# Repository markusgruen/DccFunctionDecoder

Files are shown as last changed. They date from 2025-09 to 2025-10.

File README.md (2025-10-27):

# DccFunctionDecoder

Hier klicken für deutsch: [Deutsche Doku](https://github.com/markusgruen/DccFunctionDecoder/blob/main/README_DE.md)

---

A simple DCC function decoder with 4 AUX channels. Compiles for an ATtiny402

Functionality:
- CV configurable
- 4 individual outputs
- 3 modes available for each output: FADE, BLINK, NEON
- Function mapping for F0...F20 for each output
- short and long address
- consist address

## Hardware
KiCad files are available in the `Hardware`-folder

The PCB has a size of approx. 7 by 7 mm. PCB is double-sided and only has standard components in the size of 0603 or larger to enable hand soldering of the decoder.

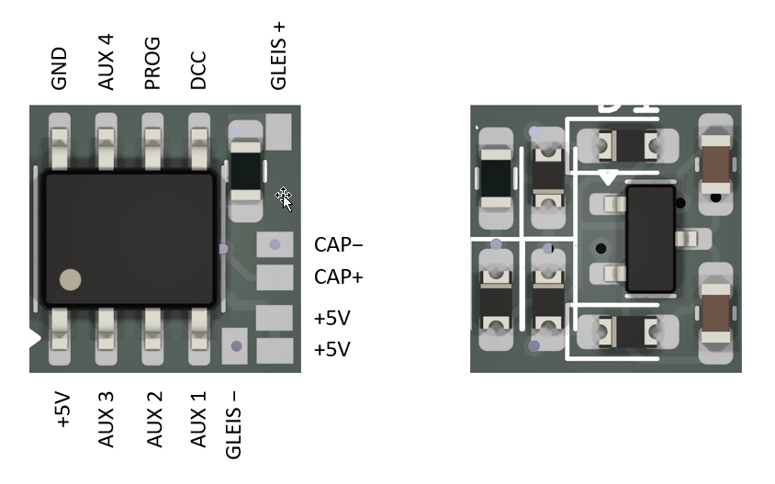
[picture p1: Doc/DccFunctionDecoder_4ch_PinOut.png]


## Software
The software can be compiled and flashed using the Arduino environment.

## Usage
### Flashing the software
You will require a standard USB-UART adapter (5V compatible). Connect the adapter as shown with the decoder. You **MUST NOT** connect the decoder's 5V with the UART-adapter. The LDO on the decoder does not like being reverse powered. Switch on the rail's power supply.

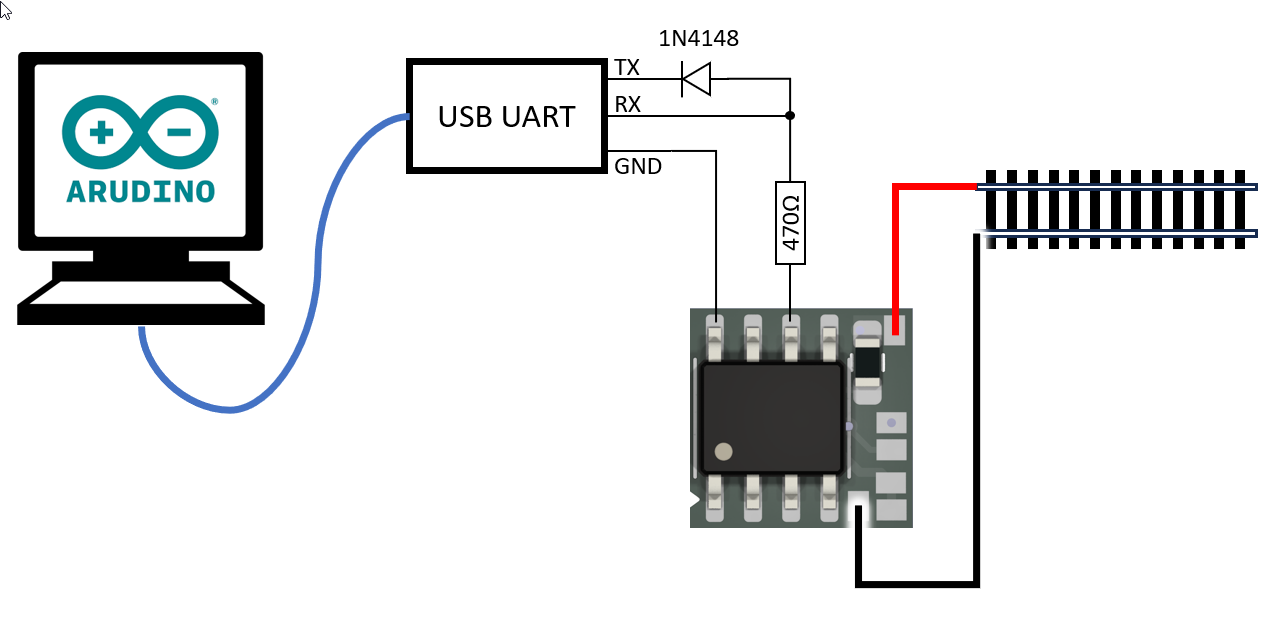
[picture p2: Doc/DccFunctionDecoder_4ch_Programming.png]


Select the appropriate COM port in the Arduino IDE and select `Sketch -> Upload using Programmer` (or hit **CTRL+SHIFT+U**). Just hitting the `Upload`-Button (or pressing **CTRL+U**) will not work.

### First usage of the decoder after flashing
Right after flashing, the Decoder is NOT yet ready for usage, as the ATtiny's EEPROM is still on factory default and the decoder therefore has an unknown address. You can already wire up the decoder as described in the following section. Then, perform a factory reset of the decoder by writing the value 8 to CV8, using the decoder's magic address 10239. In case you forgot your decoder's address, you can always perform CV writes using the magic address 10239. If you are using DecoderPro, proceed as shown below: 
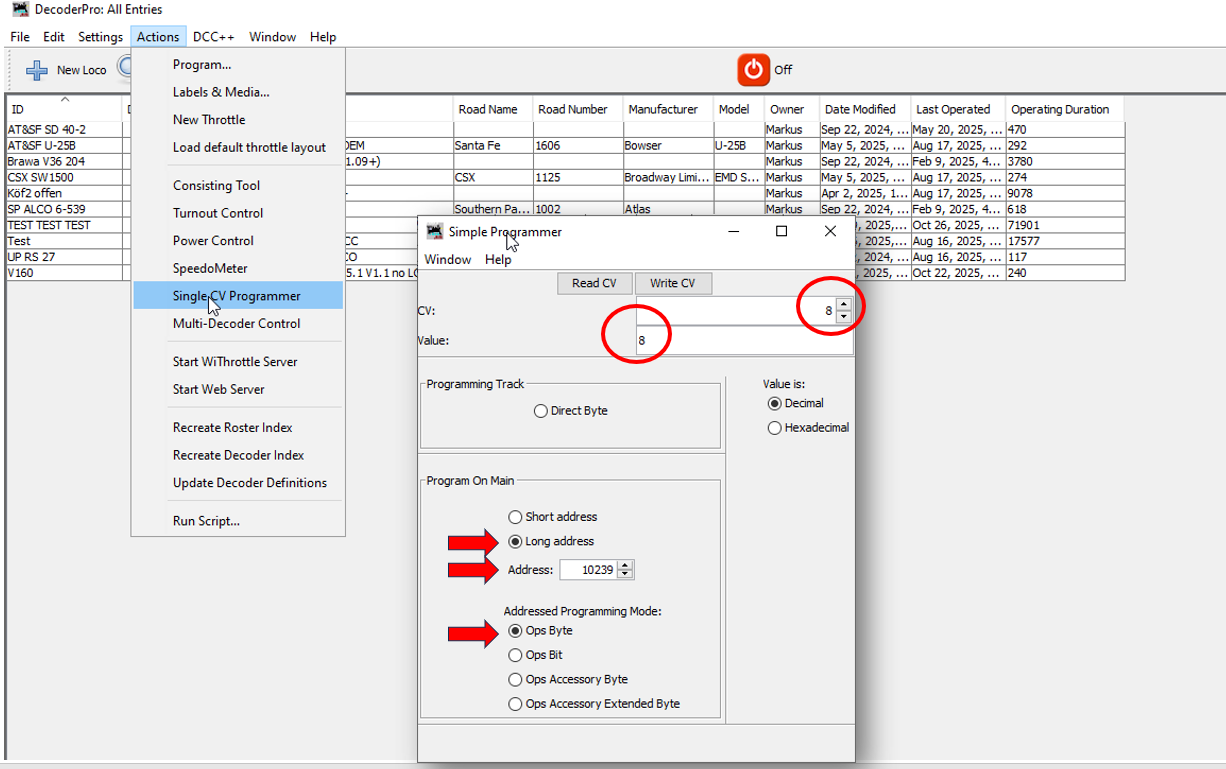
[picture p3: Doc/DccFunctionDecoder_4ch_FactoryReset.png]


### Using the decoder in a locomotive or wagon
Connect the LEDs as shown. Use appropriate resistors. The maximum current should be limited to 2 mA per LED. That does sound little but usually it is enough. Otherwise the LDO on the decoder gets too hot. 

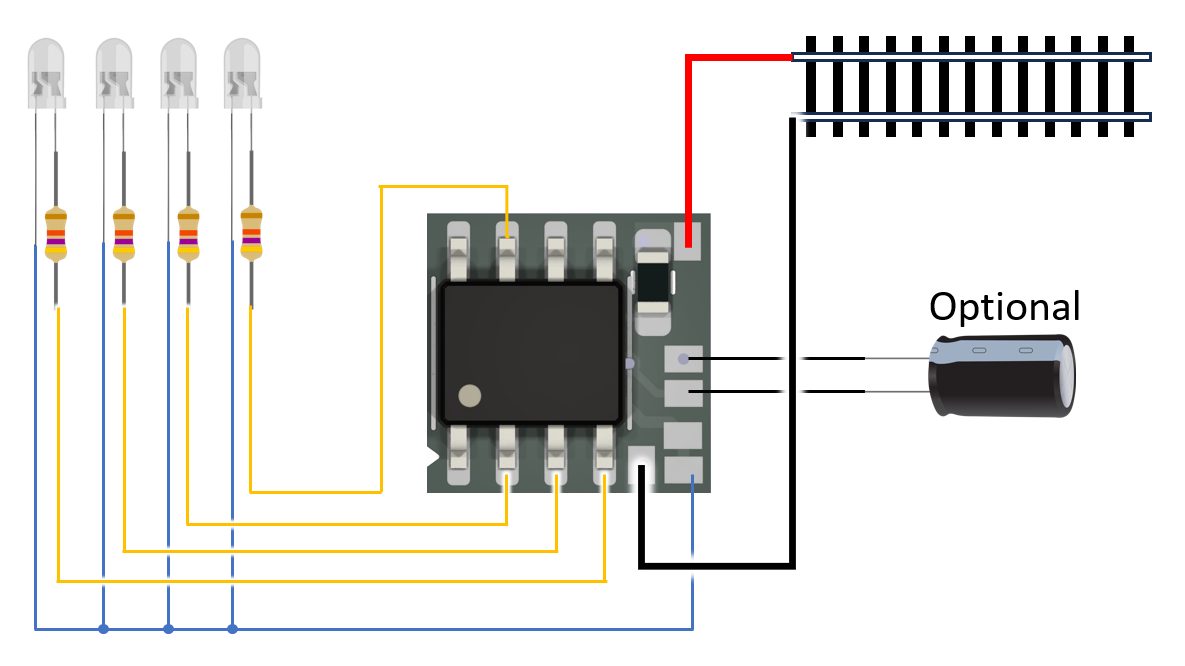
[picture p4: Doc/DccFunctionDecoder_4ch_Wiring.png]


### Programming CVs
The decoder ONLY supports Programming on Main (POM) mode. It cannot generate an ACK. For CVs see the following table below. The decoder will confirm each CV write with a short flash of all AUX channels. 

#### Programming the address
Special note on programming the address: If you want to change the decoder's address, you must do so in the following order:
1. program CV3 or CV17 and CV18 as desired.
2. program CV29 = 0 (short address) or CV29 = 32 (long address)

From then on, the decoder will only accept CV writes or commands to the new address. (it will of course still accept commands to its consist address)

#### Decoder reset
The decoder can be reset to its default CV values by writing CV8 = 8. This is confirmed by multiple short flashes of all AUX channels.

#### CV table

| CV | Type | range | default Value | Description |
|---|---|---|---|---|
| 1 | address | 1...127 | 3 | short address |
| 17 | long Address high byte | 192...255 | 195 | CV17 = 192 + (address / 256) |
| 18 | long address low byte  | 0...255 | 232 | CV18 = address mod 256 |
| 19 | consist address  | 0...255 | 0 | consist address |
| 29 | configuration byte  | 0...255 | 0 | CV29 = 0: short address;<br>CV29 = 32: long address |
| 33...35<br>36...38<br>39...41<br>42...44 | FunctionMap AUX n <br> (3 bytes for each AUX. The 3 bytes form a "word" with 24 bits)  | each CV: 0...255  | CV33 = 0b00000010 (F1) <br> CV36 = 0b00000100 (F2) <br> CV39 = 0b00001000 (F3) <br> CV42 = 0b00010000 (F4) <br> all others = 0  | Bit 0 = 1: AUX n controlled by F0<br> Bit 1 = 1: AUX n controlled by F1 <br>...<br> Bit 20 = 1 : AUX n controlled by F20 <br> Bit 21: reserved <br> Bit 22 = 1: AUX n only active when forward <br> Bit 23 = 1: AUX n only active when reverse |
| 57 <br> 58 <br> 59 <br> 60  | Output mode AUX n  | 0...2 | 0 | 0 = fade <br> 1 = neon <br> 2 = Blink |
| 65 <br> 66 <br> 67 <br> 68  | dimm value AUX n | 0...255 | 255 | 0 = off <br> ... <br> 255 = full brightness |
| 73 <br> 74 <br> 75 <br> 76  | fade speed AUX n | 0...255 | 0 | 0 = instant on/off <br> ... <br> 255 = very slow fading |
| 97 <br> 98 <br> 99 <br> 100 | blink on time AUX n  | 0...255  | 80 | value * 10ms = on-time during blink <br> (only active when CV57...60 = 2) |
| 105 <br> 106 <br> 107 <br> 108 | blink off time AUX n  | 0...255  | 150 | value * 10ms = off-time during blink <br> (only active when CV57...60 = 2) |

## License and Legal
Copyright 2025 by Markus Grün

Software licensed under GNU General Public License v3.0, see license file in `Software`-folder

Hardware (Schematics, Layout, etc.) licensed under CERN-OHL-P v2 or later, see license file in `Hardware`-folder

THE SOFTWARE AND SOURCES ARE PROVIDED "AS IS", WITHOUT WARRANTY OF ANY KIND, EXPRESS OR IMPLIED, INCLUDING BUT NOT LIMITED TO THE WARRANTIES OF MERCHANTABILITY, FITNESS FOR A PARTICULAR PURPOSE AND NONINFRINGEMENT. IN NO EVENT SHALL THE AUTHORS OR COPYRIGHT HOLDERS BE LIABLE FOR ANY CLAIM, DAMAGES OR OTHER LIABILITY, WHETHER IN AN ACTION OF CONTRACT, TORT OR OTHERWISE, ARISING FROM, OUT OF OR IN CONNECTION WITH THE SOFTWARE OR SOURCES OR THE USE OR OTHER DEALINGS IN THE SOFTWARE OR SOURCES.

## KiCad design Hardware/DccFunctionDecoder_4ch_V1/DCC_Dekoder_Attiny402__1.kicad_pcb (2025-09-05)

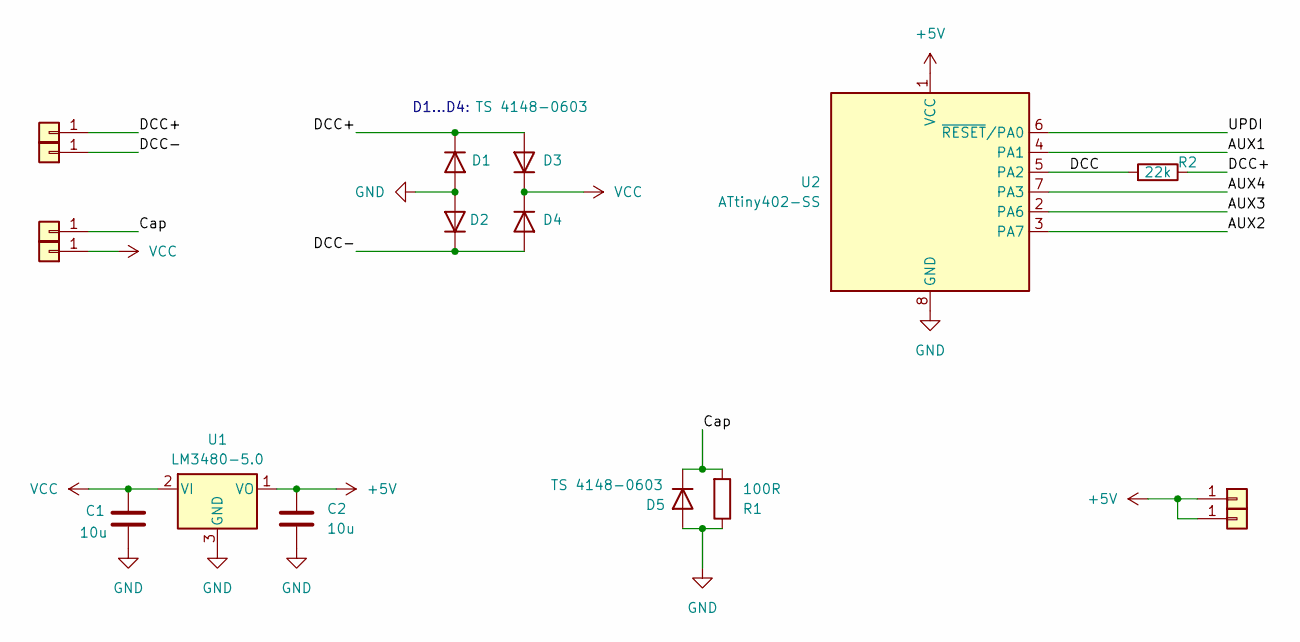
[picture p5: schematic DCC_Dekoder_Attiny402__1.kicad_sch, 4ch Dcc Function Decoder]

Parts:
C1, C2: 10u; C_0603_1608Metric_Pad1.08x0.95mm_HandSolder
D1, D2, D3, D4, D5: TS 4148-0603; D_0603_1608Metric_Pad1.05x0.95mm_HandSolder
J1, J2, J3, J4, J5, J7: Conn_01x01; Solderpad_1x_SMD_1.0x0.7
R1: 100R; R_0603_1608Metric_Pad0.98x0.95mm_HandSolder
R2: 22k; R_0603_1608Metric_Pad0.98x0.95mm_HandSolder
U1: LM3480-5.0; SOT-23
U2: ATtiny402-SS; SOIC-8_3.9x4.9mm_P1.27mm

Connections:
+5V: C2.1, J5.1, J7.1, U1.1 (VO), U2.1 (VCC)
/AUX1: U2.4 (PA1)
/AUX2: U2.3 (PA7)
/AUX3: U2.2 (PA6)
/AUX4: U2.7 (PA3)
/Cap: D5.1 (K), J2.1, R1.2
/DCC: R2.2, U2.5 (PA2)
/DCC+: D1.1 (K), D3.2 (A), J1.1, R2.1
/DCC-: D2.1 (K), D4.2 (A), J4.1
/UPDI: U2.6 (~RESET/PA0)
GND: C1.2, C2.2, D1.2 (A), D2.2 (A), D5.2 (A), R1.1, U1.3 (GND), U2.8 (GND)
VCC: C1.1, D3.1 (K), D4.1 (K), J3.1, U1.2 (VI)

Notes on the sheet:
D1...D4:

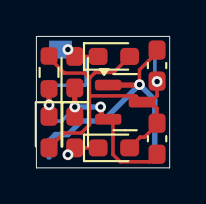
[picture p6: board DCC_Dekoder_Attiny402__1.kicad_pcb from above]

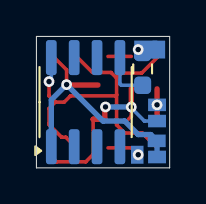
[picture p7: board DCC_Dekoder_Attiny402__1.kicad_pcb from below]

Board: 2 copper layers, 7.4 x 7.3 mm, 17 parts (8 on the bottom side), 7 nets.

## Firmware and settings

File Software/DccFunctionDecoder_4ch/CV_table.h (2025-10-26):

#ifndef CV_TABLE_H
#define CV_TABLE_H


#define DEFAULT_SHORT_ADDRESS 3
#define DEFAULT_LONG_ADDRESS 1000
#define MAGIC_ADDRESS  10239  // decoder can always be programmed using this address

//      EEPROMaddress    CV
#define SHORTADDRESS      1
#define LONGADDRESS1     17
#define LONGADDRESS2     18
#define CONSISTADDRESS   19
#define CONFIGBYTE       29

#define ch1FunctionMap0  33
#define ch1FunctionMap1  34
#define ch1FunctionMap2  35
#define ch2FunctionMap0  36
#define ch2FunctionMap1  37
#define ch2FunctionMap2  38
#define ch3FunctionMap0  39
#define ch3FunctionMap1  40
#define ch3FunctionMap2  41
#define ch4FunctionMap0  42
#define ch4FunctionMap1  43
#define ch4FunctionMap2  44
#define ch5FunctionMap0  45
#define ch5FunctionMap1  46
#define ch5FunctionMap2  47
#define ch6FunctionMap0  48
#define ch6FunctionMap1  49
#define ch6FunctionMap2  50
#define ch7FunctionMap0  51
#define ch7FunctionMap1  52
#define ch7FunctionMap2  53
#define ch8FunctionMap0  54
#define ch8FunctionMap1  55
#define ch8FunctionMap2  56

#define ch1Mode 57
#define ch2Mode 58
#define ch3Mode 59
#define ch4Mode 60
#define ch5Mode 61
#define ch6Mode 62
#define ch7Mode 63
#define ch8Mode 64

#define ch1DimmValue 65
#define ch2DimmValue 66
#define ch3DimmValue 67
#define ch4DimmValue 68
#define ch5DimmValue 69
#define ch6DimmValue 70
#define ch7DimmValue 71
#define ch8DimmValue 72

#define ch1FadeSpeed 73
#define ch2FadeSpeed 74
#define ch3FadeSpeed 75
#define ch4FadeSpeed 76
#define ch5FadeSpeed 77
#define ch6FadeSpeed 78
#define ch7FadeSpeed 79
#define ch8FadeSpeed 80

#define ch1BlinkOnTime 97
#define ch2BlinkOnTime 98
#define ch3BlinkOnTime 99
#define ch4BlinkOnTime 100
#define ch5BlinkOnTime 101
#define ch6BlinkOnTime 102
#define ch7BlinkOnTime 103
#define ch8BlinkOnTime 104

#define ch1BlinkOffTime 105
#define ch2BlinkOffTime 106
#define ch3BlinkOffTime 107
#define ch4BlinkOffTime 108
#define ch5BlinkOffTime 109
#define ch6BlinkOffTime 110
#define ch7BlinkOffTime 111
#define ch8BlinkOffTime 112
 


#endif

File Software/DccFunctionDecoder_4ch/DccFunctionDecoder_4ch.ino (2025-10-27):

#include "DccPacketHandler.h"
#include "outputController.h"

/******************************************************
  This is a DCC function decoder with 4 channel outputs
  --> https://github.com/markusgruen/DccFunctionDecoder

  Copyright (c) 2025 Markus Grün
  GNU General Public License v3.0
*****************************************************/

//   1.  install megaTinyCore: https://github.com/SpenceKonde/megaTinyCore
//   2.  select Tools -> Board -> megaTinyCore - >ATtiny412/402/212/202
//   3.  select Tools -> Chip -> ATtiny 402
//   4.  select Tools -> millis()/micros() Timer: "Disabled"
//   5.  connect UART adapter with the decoder as shown in the documentation. Don't forget to switch on power to the rails.
//   6.  select Tools -> Port -> the UART adapter's COM-port
//   7.  select Tools -> Programmer -> SerialUPDI - 230400 Baud
//   8.  select Tools -> save EEPROM (...) -> EEPROM retained
//   9.  select Tools -> Burn Bootloader  <-- you must do this once, otherwise EEPROM will get erased whenever you flash the software
//   10. select Sketch -> Upload using Programmer (CRTL+SHIFT+U)


void setup() {

  OutputController::begin();
  DccPacketHandler::begin();
  OutputController::readCVs();

}

void loop() {

  DccPacketHandler::run();
  OutputController::run(DccPacketHandler::direction, DccPacketHandler::functions);

}

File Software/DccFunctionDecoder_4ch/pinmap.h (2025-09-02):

#ifndef PINMAP_H
#define PINMAP_H

#include <Arduino.h>

// DCC input pin
#define DCC_PIN PIN2_bm

// Number of output channels
#define NUM_CHANNELS 4

// Output pins for the 4 channels
#define CH1_PIN PIN1_bm
#define CH2_PIN PIN7_bm
#define CH3_PIN PIN6_bm
#define CH4_PIN PIN3_bm

#endif

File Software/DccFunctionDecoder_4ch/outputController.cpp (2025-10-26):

#include "outputController.h"
#include "CV_table.h"
#include <Arduino.h>
#include <EEPROM.h>


// Volatile variables
volatile uint8_t vPwmValue[NUM_CHANNELS] = {0};
volatile uint8_t vRtcOverflowCounter; 

// Global variables
const uint8_t channelPin_bm[NUM_CHANNELS] = {CH1_PIN, CH2_PIN, CH3_PIN, CH4_PIN};
uint8_t flackerCount[NUM_CHANNELS];



namespace OutputController{
  uint32_t functionMap[NUM_CHANNELS];
  uint8_t dimmValue[NUM_CHANNELS];
  uint8_t fadeSpeed[NUM_CHANNELS];
  uint8_t blinkOnTime[NUM_CHANNELS];
  uint8_t blinkOffTime[NUM_CHANNELS];
  Mode mode[NUM_CHANNELS];
  Direction direction;
  bool channelState[4] = {0};

  /**
   * @brief Initialize output pins, PWM timer and RTC (for blink waits).
   */
  void begin(){
    // configure output pins
    PORTA.DIRSET = (CH1_PIN | CH2_PIN | CH3_PIN | CH4_PIN);
    PORTA.OUTSET = (CH1_PIN | CH2_PIN | CH3_PIN | CH4_PIN);


    // setup Timer A for software-PWM with >100Hz frequency at 8bit resolution
    // 20 MHz → 1 Takt = 0.05 µs → 30 µs = 600 Takte
    TCB0.CCMP = 599;                   // 600 Takte @ 20 MHz = 30 µs
    TCB0.INTCTRL = TCB_CAPT_bm;        // enable Interrupt
    TCB0.CTRLA = TCB_ENABLE_bm;        // enable Timer (no prescaler = CLK_PER)

    // setup RTC for 10 ms Interrupt
    RTC.PER = 16;                                       // period = 16 ticks ~= 0.5 ms
    RTC.INTCTRL = RTC_OVF_bm;                           // activate overflow interrupt
    RTC.CTRLA = RTC_PRESCALER_DIV1_gc | RTC_RTCEN_bm;   // Prescaler 1, start RTC
  }

  /**
   * @brief Load stored CV values from EEPROM into live code.
   */
  void readCVs() {
    for(uint8_t i=0; i<NUM_CHANNELS; i++) {
      functionMap[i]  = (uint32_t)EEPROM.read(ch1FunctionMap0 + (i*3));
      functionMap[i] |= (uint32_t)EEPROM.read(ch1FunctionMap1 + (i*3)) << 8;
      functionMap[i] |= (uint32_t)EEPROM.read(ch1FunctionMap2 + (i*3)) << 16;

      mode[i] = (Mode)EEPROM.read(ch1Mode + i);
      dimmValue[i] = EEPROM.read(ch1DimmValue + i);
      fadeSpeed[i] = EEPROM.read(ch1FadeSpeed + i);
      blinkOnTime[i] = EEPROM.read(ch1BlinkOnTime + i);
      blinkOffTime[i] = EEPROM.read(ch1BlinkOffTime + i);
    }
  }

  /**
   * @brief Execute channel logic for all outputs.
   */
  void run(Direction direction, uint32_t functions) {  
    for(uint8_t channel = 0; channel < NUM_CHANNELS; channel++) {
      bool switch_on = (isChannelOn(functions, channel) && directionMatchesConfig(channel, direction));

      switch(mode[channel]) {
        case FADE:
          fade(channel, switch_on);
          break;

        case BLINK:
          blinkStateMachine(channel, switch_on);
          break;

        case NEON:
          neonStateMachine(channel, switch_on);
          break;
      }
    }
  }

  
  
  /**
   * @brief Blink state machine with fade in/out.
   */
  void blinkStateMachine(uint8_t channel, bool switch_on) {
    enum BlinkStates{BLINK_OFF, BLINK_WAIT_OFF, BLINK_FADE_IN, BLINK_WAIT_ON, BLINK_FADE_OUT};
    static BlinkStates blinkState[NUM_CHANNELS] = {BLINK_OFF};

    if(switch_on) {
      switch(blinkState[channel]) {
        case BLINK_OFF:
          blinkState[channel] = BLINK_FADE_IN;
          break;
        
        case BLINK_FADE_IN:
          if(fade(channel, 1)) {
            blinkState[channel] = BLINK_WAIT_ON;
          }
          break;

        case BLINK_WAIT_ON:
          if(wait(channel, blinkOnTime[channel])) { // if wait_is_over
            blinkState[channel] = BLINK_FADE_OUT;
          }
          break;

        case BLINK_FADE_OUT:
          if(fade(channel, 0)) {
            blinkState[channel] = BLINK_WAIT_OFF;
          }
          break;
        
        case BLINK_WAIT_OFF:
          if(wait(channel, blinkOffTime[channel])) { // if wait_is_over
             blinkState[channel] = BLINK_FADE_IN;
             flackerCount[channel]++;
          }
          break;
      }
    }
    else { // if (switch_off)
      wait(channel, 0, true);  // reset wait
      if(fade(channel, 0)) {
        blinkState[channel] = BLINK_OFF;
      }
    }
  }

  /**
   * @brief Neon lamp effect with flicker and fade-in.
   */
  void neonStateMachine(uint8_t channel, bool switch_on) {
    enum NeonStates{NEON_OFF, NEON_FLICKER, NEON_FADE_IN, NEON_CONSTANT_ON};
    static NeonStates neonState[NUM_CHANNELS] = {NEON_OFF};
    blinkOnTime[channel] = 2;

    if(switch_on) {
      switch(neonState[channel]) {
        case NEON_OFF:
          flackerCount[channel] = 0;
          fadeSpeed[channel] = 0;
          neonState[channel] = NEON_FLICKER;
          break;
        
        case NEON_FLICKER:
          if(flackerCount[channel] <= myRandomNumber(6, 38)) {
            blinkOffTime[channel] = myRandomNumber(2,48); 
            blinkStateMachine(channel, 1);
          }
          else {
            vPwmValue[channel] = dimmValue[channel]/16;
            fadeSpeed[channel] = 20; // langsames faden    
            neonState[channel] = NEON_FADE_IN;
          }
          break;

        case NEON_FADE_IN:
          if(fade(channel, 1)) {
            neonState[channel] = NEON_CONSTANT_ON;
          }
          break;

        case NEON_CONSTANT_ON:
          break;        
      }
    }

    else { // if(switch_off)
      fadeSpeed[channel] = 1;
      if(fade(channel, 0)) {
        neonState[channel] = NEON_OFF;
      }
    }
  }

  /**
   * @brief Fade PWM output gradually to target value.
   * @return true if fade finished.
   */
  bool fade(uint8_t channel, bool fade_in) {
    enum FadeStates{FADE_START, FADE_RUNNING};
    static FadeStates fadeState[NUM_CHANNELS] = {FADE_START};
    static uint8_t nextEvent[NUM_CHANNELS] = {0};

    uint8_t targetDimmValue = fade_in ? dimmValue[channel] : 0;
    
    if(fadeSpeed[channel] == 0) {      
      vPwmValue[channel] = targetDimmValue;
      fadeState[channel] = FADE_START;
      return true;
    }
    else if(vPwmValue[channel] == targetDimmValue) {
      fadeState[channel] = FADE_START;
      return true;
    }
    else {
      if(fadeState[channel] == FADE_START) {
        nextEvent[channel] = vRtcOverflowCounter;
        fadeState[channel] = FADE_RUNNING;
      }

      if(fadeState[channel] == FADE_RUNNING) {
        uint8_t overflowCounter = vRtcOverflowCounter;
        if(overflowCounter == nextEvent[channel]) {
          nextEvent[channel] += fadeSpeed[channel];
          if (vPwmValue[channel] == targetDimmValue){ 
            fadeState[channel] = FADE_START;
            return true;
          }
          fade_in ? vPwmValue[channel]++ : vPwmValue[channel]--;
        }
      }
    }
    return false;
  }

  /**
   * @brief Non-blocking wait function - waits (10 ms * waitTime);
   * @return true when wait has elapsed.
   */
  bool wait(uint8_t channel, uint8_t waitTime, bool reset){
    static uint8_t stopTime[NUM_CHANNELS] = {0};
    static uint8_t waitCounter[NUM_CHANNELS] = {0};
    
    if(reset){
      waitCounter[channel] = 0;
      return true;
    }
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

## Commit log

2025-09-02 Release of V0.1
    [DCC_Dekoder_Attiny402__1.kicad_pcb, DCC_Dekoder_Attiny402__1.kicad_sch]
2025-09-05 fix component values in schematics
    [DCC_Dekoder_Attiny402__1.kicad_pcb, DCC_Dekoder_Attiny402__1.kicad_sch]
2025-10-23 Bug in schematic for programming fixed (UART-GND now connects to Attiny-GND)
2025-10-26 Bugfix: added magic address that enables CV programming of a new processor.
    [CV_table.h, DccFunctionDecoder_4ch.ino, DccPacketHandler.cpp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]
2025-11-02 Bugfix: 1. Decoder now responds when placed either way on the tracks 2. Decoder only responds to addresses > 0
    [DccPacketHandler.cpp]
